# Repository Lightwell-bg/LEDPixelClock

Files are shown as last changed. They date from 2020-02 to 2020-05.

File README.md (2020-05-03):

# LED Pixel Clock (Clock, alarms, temperature, humidity, atmospheric pressure, and remote monitoring)
Multifunctional clock based on ESP8266 and WS2811 addressable LEDs for Home Automation (IoT)

------------
## What is a LED Pixel Clock?
The LED Pixel Clock is a four digit clock made up of 30 WS2811 addressable LEDs (8 mm) arranged into a 7-segment display. It based on ESP8266 microcontroller and real-time clock DS3231. BME280 sensor provides a precise measurement of indoor temperature, humidity and barometric pressure. An Internet connection via Wi-Fi module helps to synchronize time with NTP servers. Data from sensors can be transmitted via MQTT protocol or displayed on popular monitoring service thingspeak.com. Clock adjustment and manipulation is performed via WEB-interface.

# Features include:
- Always precise time because of synchronization with NTP time servers
- Indoor temperature, humidity and barometric pressure measurement
- Sending temperature, humidity and barometric pressure data to MQTT and Thingspeak.com server
- No buttons – control the clock via WEB-interface from PC, tablet or smartphone
- High display brightness
- Seven colors to display information
- Brightness adjustment
- Two alarm clocks
- Firmware update via Wi-Fi
- Information display on 3 languages: English, Russian, Bulgarian
- An option to install different alternative Open Source firmware
- Powered via USB
- Hackable: Open source hardware and firmware, Displays information read via UART

## Required Parts:
- Wemos D1 Mini: http://got.by/40d3u7
- RGB LED with WS2811 8mm http://ali.pub/4h4ehf
- BME280 Digital Sensor (Temperature, Humidity, Barometric Pressure) 5V: http://got.by/40d52x
- TTP223B digital touch capacitive sensor: http://got.by/40d6kz
- DS3231 AT24C32 IIC Module Precision Clock http://got.by/42k10g
- Active Buzzer http://got.by/42k1sg

Note: Using the links provided here help to support these types of projects. Thank you for the support.

**You can purchase a PCB with soldered elements and connectors for connecting the indicator and sensors, or just a PCB and a set of elements for installation**
https://diy.led-lightwell.eu/product/led-pixel-clock-shield-for-esp8266/

## Schematics / Assembly
| Component  | Pins  |  Wemos D1 Mini |
| --- | --- | --- |
| **RGB LED with WS2811**  |  Din -->|D5 (GPIO14)|
||+5V -->||
||GND --> | |
|**DS3231**|SCL -->|D1 (GPIO5)|
||SDA -->|D2 (GPIO4)|
||+3V||
||GND||
|**BME280**|SCL -->|D1 (GPIO5)|
||SDA -->|D2 (GPIO4)|
||+5V||
||GND||
|**Buzzer (active)**|+ -->|D8 (GPIO15)|
||GND||
|**TTP223B digital touch capacitive  sensor**|Dout -->|D6 (GPIO12)|
||+5V||
||GND||

## Power Supply
You must use a power supply 5V with a capacity of 2 A or more.

## Loading Supporting Library Files in Arduino
The following packages and libraries are used (download and install):
- ArduinoJson by Benoit Blanchon (version 6.13.0)
- TimeLib by Paul Stoffregen (version 1.5)
- PubSubClient by Nick O'Leary (version 2.7)
- RTClib by Adafruit  (version 1.3.3)
- Adafruit Unified Sensor by Adafruit (version 1.0.3) (for DHT sensor only)
- DHT sensor library by Adafruit (version 1.3.8) (for DHT sensor only)
- BlueDot BME280 Library by BlueDot (version 1.0.9)
- NetCrtESP (version 1.0) https://github.com/Lightwell-bg/NetCrtESP
- ESPTimeFunc (version 1.0) https://github.com/Lightwell-bg/ESPTimeFunc

Note: There could be some Issues if using different versions of the libraries.

## Initial Configuration
Starting with LW-Clock editing the Config.h file is optional. SSID and password for Wi-Fi, all API Keys are managed in the Web Interface. It is not required to edit the Config.h file before loading and running the code.
This project requires SPIFFS for saving and reading configuration settings
Use an external power supply with a capacity of 2 A or more!
**NOTE:** The settings in the Config.h are the default settings for the first loading. After loading you can change the settings via the Web Interface. If you want to change settings again in the Config.h, you will need to erase the file system on the Wemos or use the “Reset Settings” option in the Web Interface. During the first time run, Wemos D1 mini will try to connect to your Wi-Fi and fail (because it doesn't have any previously saved Wi-Fi credentials). This will cause it to start up an access point, which serves up a captive configuration portal. You can connect to this access point to select and enter credentials for your network. Save configuration and restart device. (Wemos D1 mini will restart and connect to your Wi-Fi network)

## Web Interface
All clock management is carried out using a web browser. On first power-up, LED Pixel Clock will serve a hotspot called LW-Clock. For clock adjustment and manipulation open a webpage with the 192.168.4.1 address. Within this hotspot you can manually override the time and date, set color, set timecodes of messages output and update software.

For Wi-Fi network connection please input its SSID and password. After successful connection LED Pixel Clock will begin to receive and transmit information over the Internet. NTP servers are used to get accurate time. To transmit temperature, humidity and barometric pressure data you can use the MQTT server https://www.cloudmqtt.com/ and the server https://thingspeak.com.

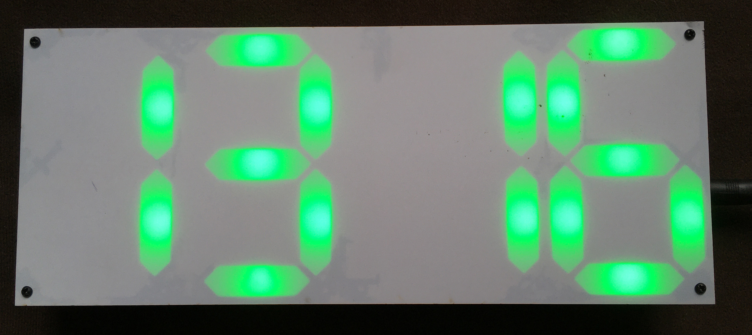
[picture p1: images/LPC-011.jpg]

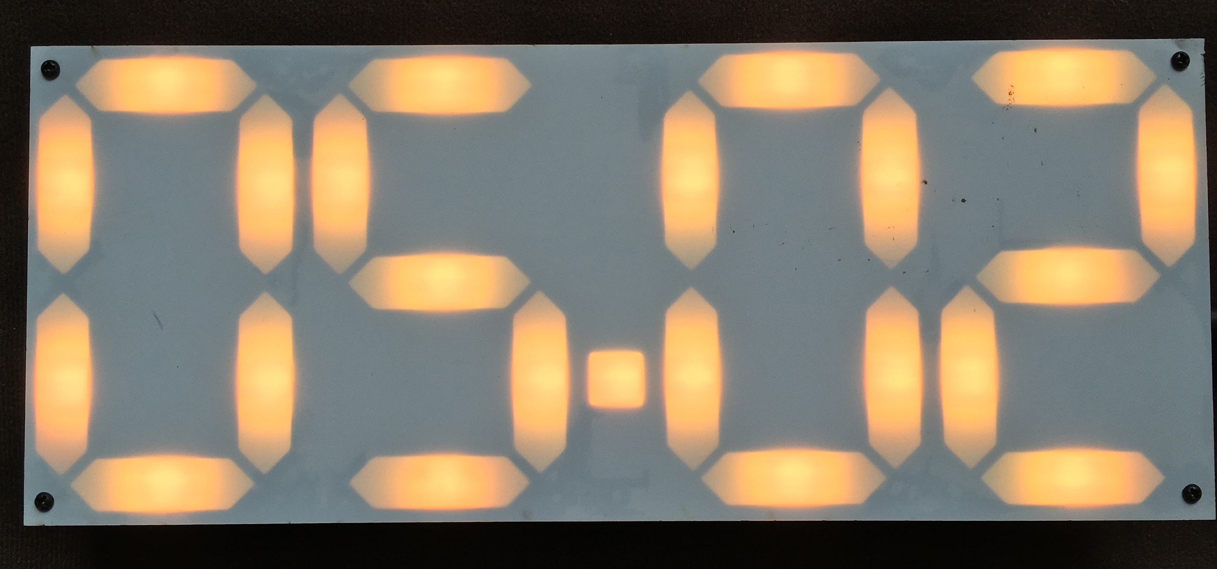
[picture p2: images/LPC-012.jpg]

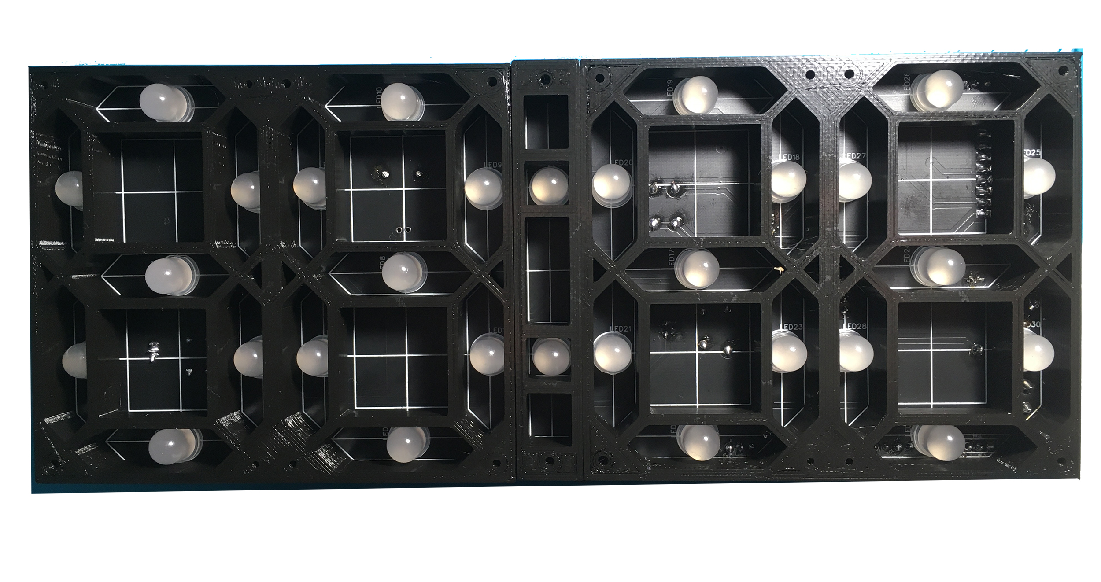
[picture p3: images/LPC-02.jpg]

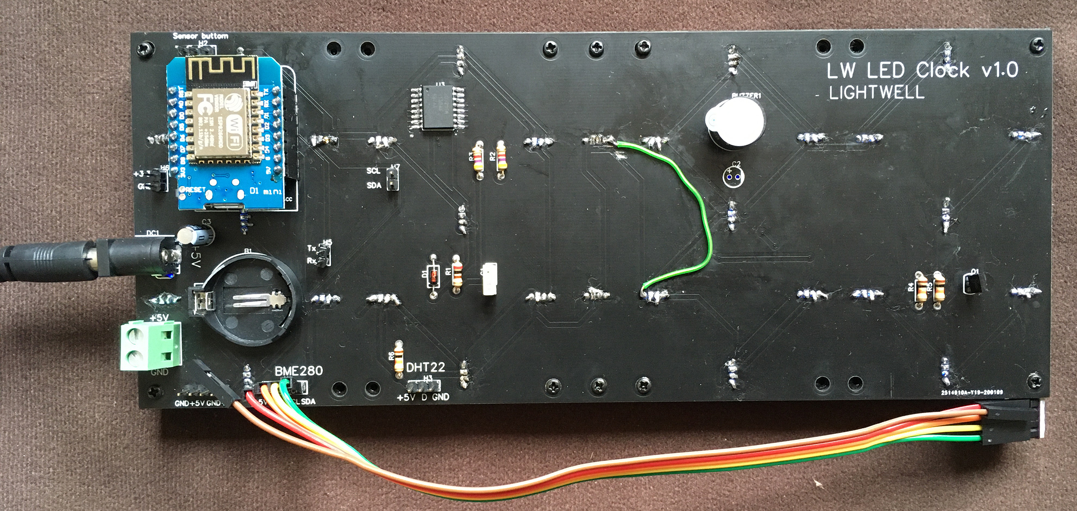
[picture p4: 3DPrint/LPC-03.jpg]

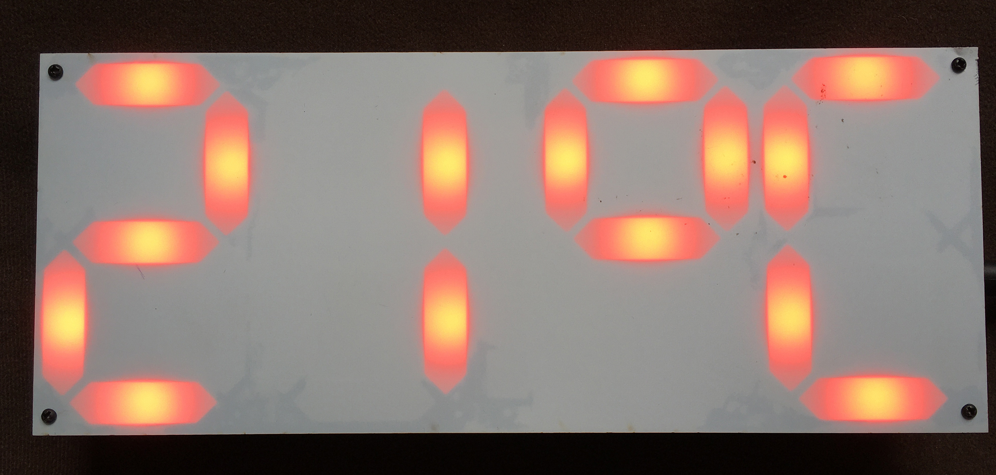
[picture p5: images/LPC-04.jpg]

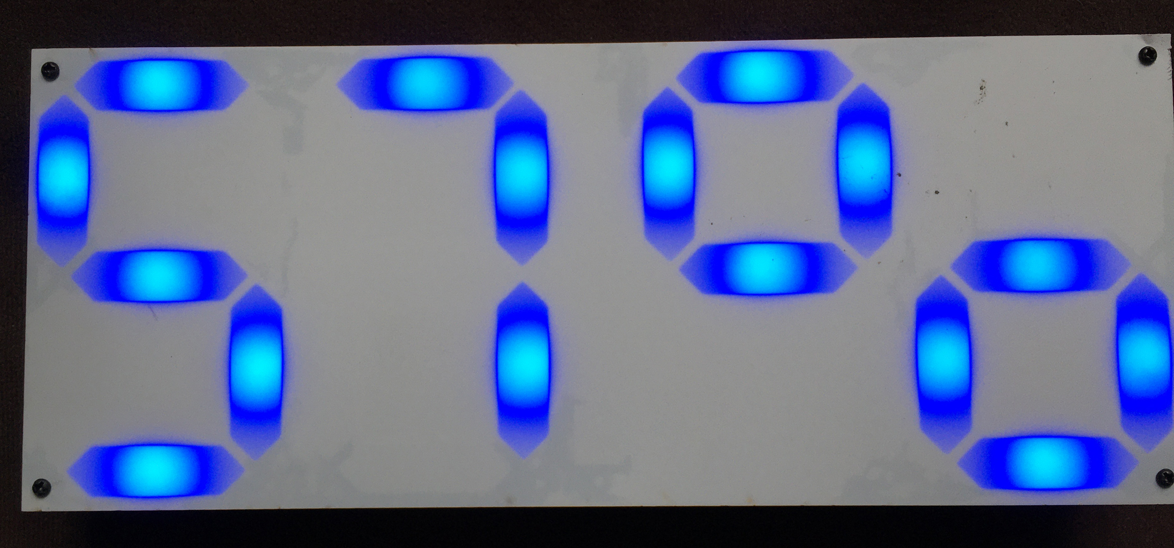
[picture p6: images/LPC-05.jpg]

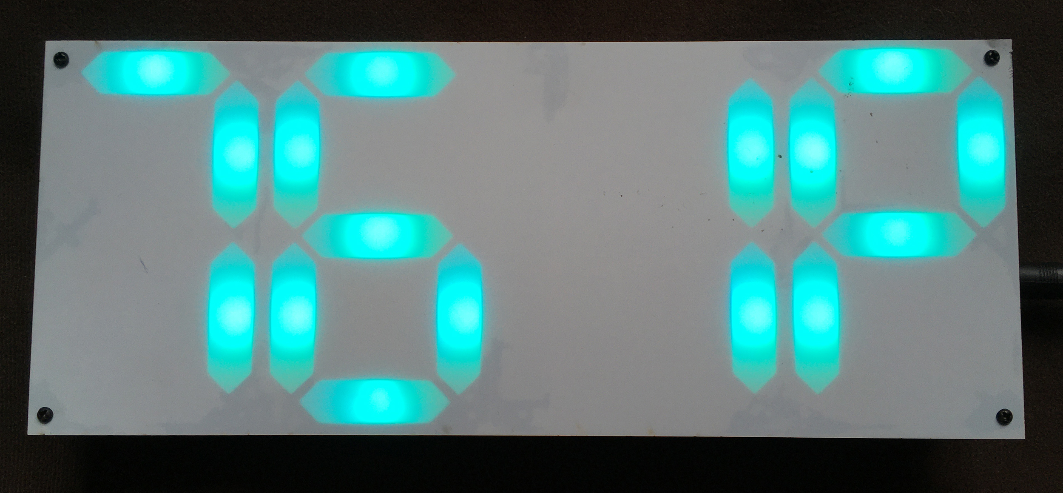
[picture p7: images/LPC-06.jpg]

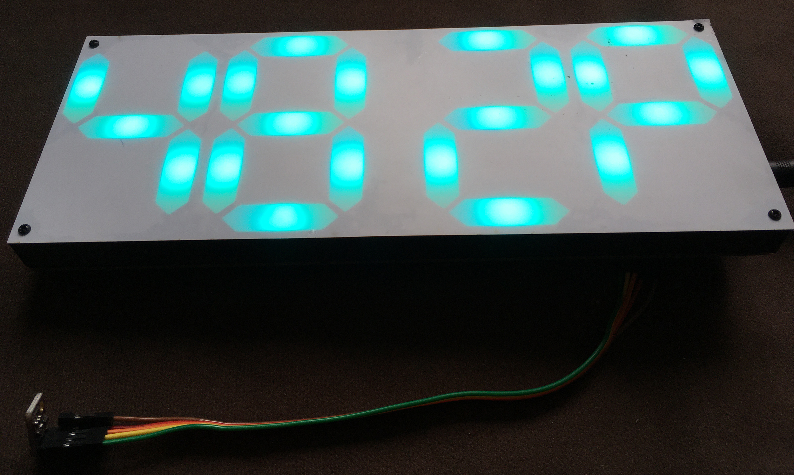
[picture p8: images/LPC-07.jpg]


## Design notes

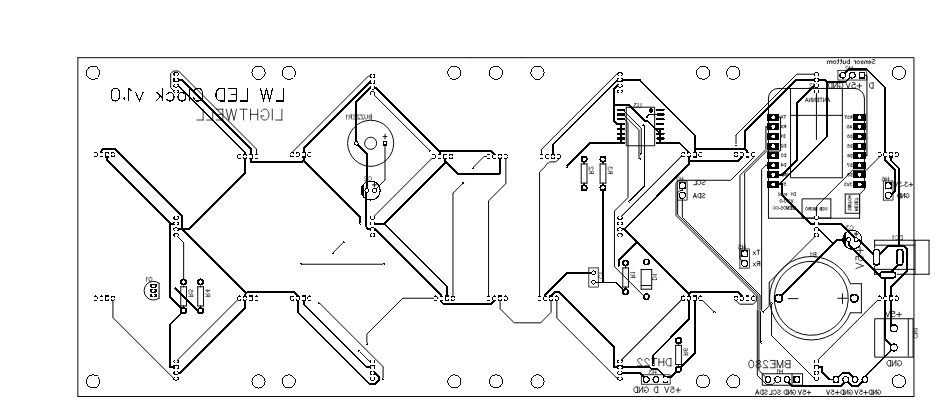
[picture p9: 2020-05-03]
Schematic&PCB/PCB2.png

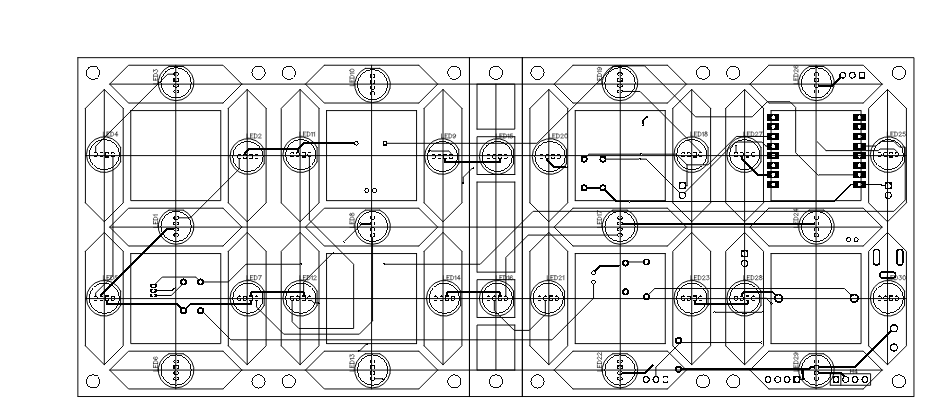
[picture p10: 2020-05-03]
Schematic&PCB/PCB1.png

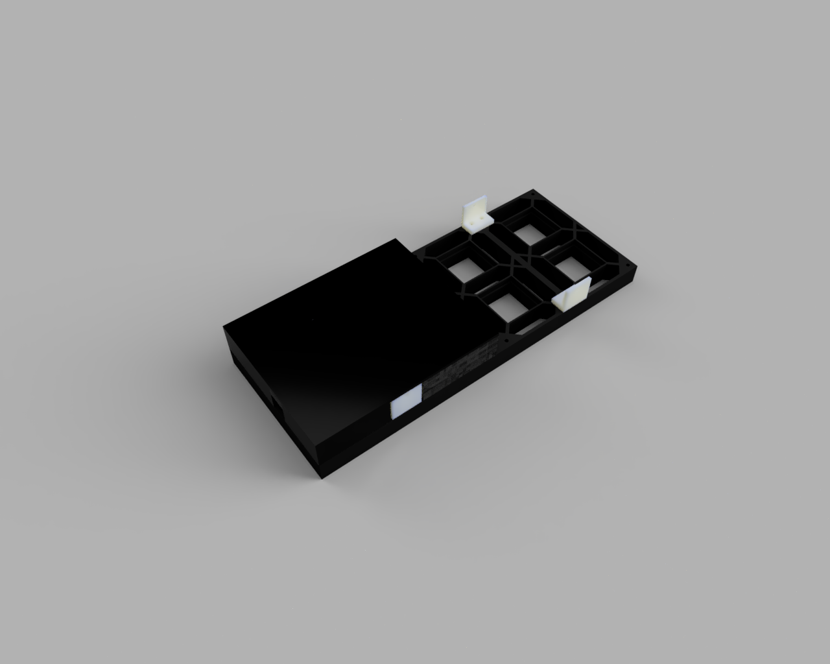
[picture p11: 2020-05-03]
images/rander.png

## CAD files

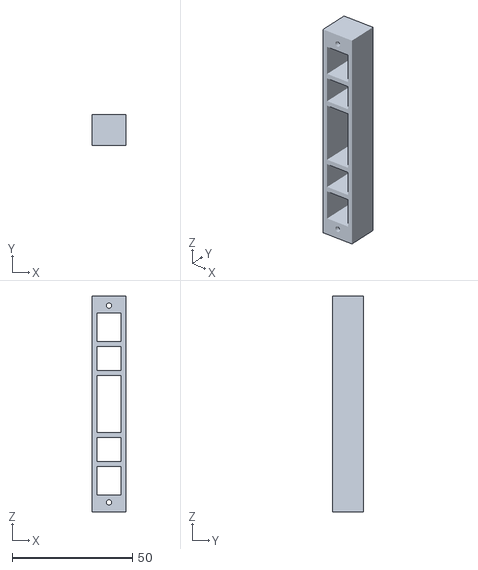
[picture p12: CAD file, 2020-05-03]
3DPrint/Dot.stl
14.0 x 13.0 x 89.7

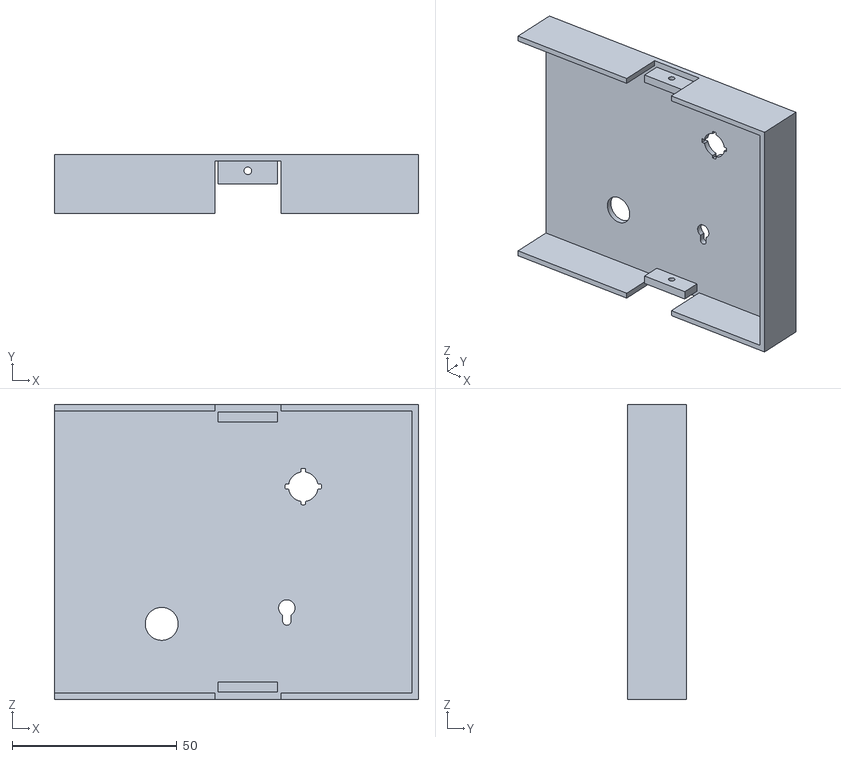
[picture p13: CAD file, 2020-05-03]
3DPrint/Back2.stl
110.6 x 18.0 x 89.7

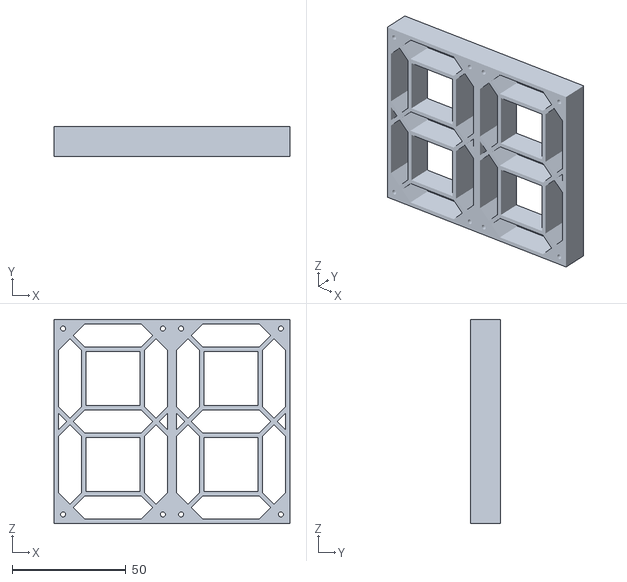
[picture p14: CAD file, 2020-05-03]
3DPrint/Segment2.stl
103.7 x 13.0 x 89.7

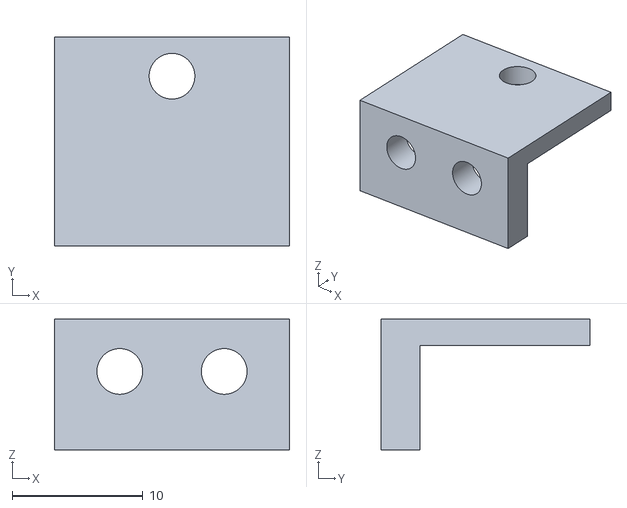
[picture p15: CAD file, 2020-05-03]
3DPrint/Part1-4.stl
18.0 x 16.0 x 10.0

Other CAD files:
3DPrint/Back1.stl

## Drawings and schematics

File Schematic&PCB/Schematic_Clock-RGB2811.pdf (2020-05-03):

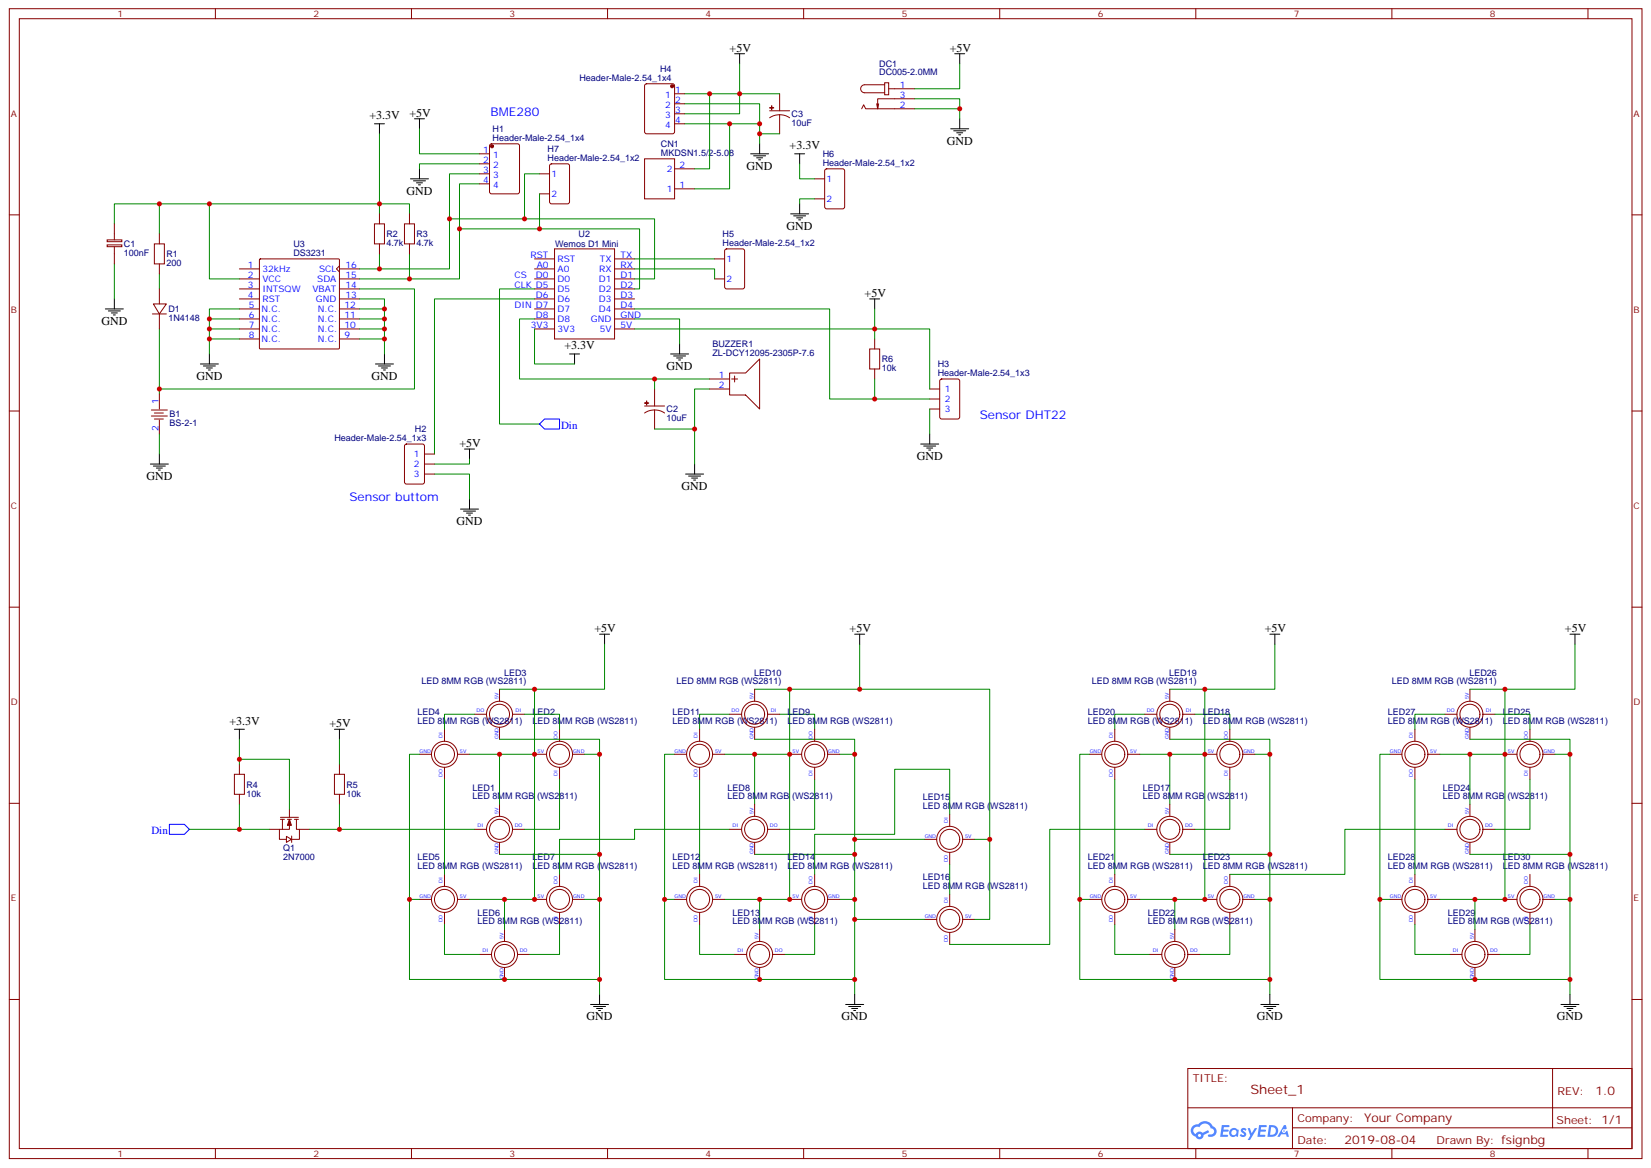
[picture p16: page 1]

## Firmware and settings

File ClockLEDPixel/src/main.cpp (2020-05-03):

#include <Arduino.h>
#include "config.h" 
#include "configFile.h"
#include "sensor.h"
#include "httpServer.h"
#include "mqtt.h"
#include "thingspeak.h"
#include "display.h"
#include "fwareupd.h"

void setup() {
    Serial.begin(115200);
    char host[16];
    snprintf(host, 12, "ESP%08X", ESP.getChipId());    
    if(!SPIFFS.begin()) { // Initialize SPIFFS
        Serial.println("An Error has occurred while mounting SPIFFS");
        return;
    } 
    loadConfig(); Serial.println(F("FileConfig init"));
    myWIFI.begin(ssid.c_str(), password.c_str(), SSDP_Name.c_str(), ssidAP.c_str(), passwordAP.c_str(), apIP.c_str()); Serial.println(F("Wi-Fi init"));
    Serial.printf("Ready! Open http://%s.local in your browser\n", host); 
    myESPTime.begin(timezone, isDayLightSaving, sNtpServerName, sNtpServerName2, sNtpServerName3, useRTC, updateRTCfromNTP); Serial.println(F("Start Time"));
    //myESPTime.setTimeRule(Last, Sun, Oct, 3, timezone*SECS_PER_HOUR, Last, Sun, Mar, 2, timezone*SECS_PER_HOUR+daylightOffset_sec);  
    init_firmWareUpdate(); Serial.println(F("Start init FirmWare update"));
    SSDP_Name = myWIFI.getNameSSDP(); Serial.println(SSDP_Name);
    mySSDP.begin(SSDP_Name.c_str(), "000000001", modelName.c_str(), nVersion.c_str(), "LIGHTWELL", "https://diy.led-lightwell.eu"); Serial.println(F("Start init SSDP"));
    init_HTTPServer(); Serial.println(F("HTTPServer init"));
    Serial.println(myWIFI.getDevStatusIP()); 
    init_sensor(); Serial.println(F("Sensor init"));
    init_mqtt();
    init_LStrip();  Serial.println(F("LED strip init"));
}

void loop() {
  struct tm tnow = myESPTime.getTimeStruct();
  static uint8_t sMode=0, oldsMode = 1;
  static uint32_t tCount = 0;
  static bool chMode = true;
  if (myESPTime.compTimeInt(global_start, global_stop, &tnow)) {
    if (sMode != oldsMode) {Serial.print(F("Mode ")); Serial.println(sMode); oldsMode = sMode;}
    if (myESPTime.compTimeInt(dmodefrom, dmodeto, &tnow))
        strip.setBrightness(map(brightd, 0, 15, 100, 255));
        else strip.setBrightness(map(brightn, 0, 15, 100, 255));
    if (millis()-tCount > intShowData) {sMode++; chMode = true; tCount = millis();}
    if (onlyClockNight && !myESPTime.compTimeInt(dmodefrom, dmodeto, &tnow)) sMode = 1; //Show only Clock Night
      if (sMode > maxMode) {sMode = 1;}
      if (sMode==1) {
        if (isLedClock && myESPTime.compTimeInt(clockFrom, clockTo, &tnow)) {
          showTime();
        }
        else sMode++;
      }
      if (sMode==2 && chMode) {
        if (isLedDate && myESPTime.compTimeInt(dateFrom, dateTo, &tnow)) {
          showDate(); chMode = false;
        }
        else sMode++;
      }
      if (sMode==3 && chMode) {
        if (isLedTemp && myESPTime.compTimeInt(tempFrom, tempTo, &tnow)) {        
          showTemp(); chMode = false;
        }
        else sMode++;
      }
      if (sMode==4 && chMode) {
        if (isLedHum && myESPTime.compTimeInt(humFrom, humTo, &tnow)) {        
          showHum(); chMode = false;
        }
        else sMode++;
      }
      if (sMode==5 && chMode) {
        if (isLedPres && myESPTime.compTimeInt(presFrom, presTo, &tnow)) {        
          showPres(); chMode = false;
        }
        else sMode++;
      }
  }
  if (tspeakOn) {
      sendTspeak(TSPEAK_SEND_INT);
  }
  if (mqttOn) {
      mqttReconnect(60000);
      sendTHP(MQTT_SEND_INT);
  }
  delay(1); //Вроде нужна для восстановления стека
  yield();
}

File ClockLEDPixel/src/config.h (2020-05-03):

#ifndef GLOBAL_H
#define GLOBAL_H
const String modelName = "LEDPixelClock";
const String nVersion = "v1.0";
#define USE_DHT false //USE OR NO
#define USE_BME280 true //USE OR NO

#include <ESP8266WiFi.h>
#include <ESPAsyncTCP.h>
#include "FS.h"
#include <Updater.h>//for update firmware
#include <ESP8266SSDP.h>
#include <ESPAsyncWebServer.h>
#include <ArduinoJson.h>
#include <SPI.h>
#include <Wire.h> // must be included here so that Arduino library object file references work
#include <PubSubClient.h> //"https://github.com/knolleary/pubsubclient.git"
#include <Adafruit_NeoPixel.h>
#include "NetCrtESP.h"
#include "ESPTimeFunc.h"
#include "ssdpAWS.h"

bool useRTC = true; //get time RTC

AsyncWebServer HTTP(80);
WiFiClient ESPclient;
PubSubClient mqttClient(ESPclient);
NetCrtESP myWIFI;
ESPTimeFunc myESPTime(useRTC);
ssdpAWS mySSDP(&HTTP);

String cVersion = modelName + nVersion;

#if USE_DHT == true
  #include <Adafruit_Sensor.h> // https://github.com/adafruit/Adafruit_Sensor
  #include "DHT.h" //https://github.com/adafruit/DHT-sensor-library
  //#define DHTTYPE DHT21   // DHT 21 (AM2301)
  #define DHTTYPE DHT22   // DHT 22  (AM2302), AM2321
  #define TEMPHUM_PIN 4    // D4 выберите входной контакт,к которому подключен датчик
  DHT dht(TEMPHUM_PIN, DHTTYPE);
  //cVersion += " DHT22 ";
#endif //DHT
#if USE_BME280 == true // I2C D1, D2
  #include "BlueDot_BME280.h"
  BlueDot_BME280 bme280 = BlueDot_BME280(); 
  //cVersion += String(" BME280"); 
#endif //BME280
  
#define LED_PIN 14 // D5
#define LED_COUNT 30 //7*4+2
Adafruit_NeoPixel strip(LED_COUNT, LED_PIN, NEO_RGB + NEO_KHZ800);

String filePath = "/myConfig.json"; //File for config
String jsonConfig = "{}";

// wifi
String ssid = "";
String password = "";
String ssidAP = "LED2811";   // SSID AP точки доступа
String passwordAP = ""; // пароль точки доступа
String SSDP_Name = "LED2811"; // Имя SSDP
//IPAddress apIP(192, 168, 4, 1);
String apIP = "192.168.4.1";

uint8_t lang = 2; //0-RU, 1-BG, 2 -EN, 3-UA
//Time
//const unsigned long TIME_UPDATE = 1000*60*10; //Интервал обновления времени
int8_t timezone = 2;               // часовой пояс GTM
String sNtpServerName = "us.pool.ntp.org";
const char sNtpServerName2[] = "pool.ntp.org";
const char sNtpServerName3[] = "time.nist.gov";
bool isDayLightSaving = false; //Summer time use
bool updateRTCfromNTP = true; //


//LED Strip
uint8_t maxMode = 5;
uint32_t intShowData = 3000;
uint8_t clockColor = 2;
uint8_t dateColor = 1;
uint8_t tempColor = 3;
uint8_t humColor = 4;
uint8_t presColor = 5;
const uint32_t offColor = strip.Color(0, 0, 0);
uint8_t digits[14][7] = {{0,1,1,1,1,1,1},  // Digit 0
                        {0,1,0,0,0,0,1},   // Digit 1
                        {1,1,1,0,1,1,0},   // Digit 2
                        {1,1,1,0,0,1,1},   // Digit 3
                        {1,1,0,1,0,0,1},   // Digit 4
                        {1,0,1,1,0,1,1},   // Digit 5
                        {1,0,1,1,1,1,1},   // Digit 6
                        {0,1,1,0,0,0,1},   // Digit 7
                        {1,1,1,1,1,1,1},   // Digit 8
                        {1,1,1,1,0,1,1},  // Digit 9 | 2D Array for numbers on 7 segment
                        {1,1,1,1,0,0,0},   // ° char
                        {0,0,1,1,1,1,0},   // C char
                        {1,0,0,0,1,1,1},  // % char
                        {1,1,1,1,1,0,0}};  // P char
uint8_t brightd = 15, brightn = 2; //brightness day and night
uint8_t dmodefrom = 8, dmodeto = 20; //DAY MODE
bool autoBright = false; //reserv
//show
bool onlyClockNight = false;
bool isLedClock = true, isLedDate = true, isLedTemp = true, isLedHum = false, isLedPres = false;
float clockFrom=0, dateFrom=0, tempFrom=0, humFrom=0, presFrom=0;
float clockTo=24, dateTo=24, tempTo=24, humTo=24, presTo=24; 
float global_start = 0, global_stop = 24; //Working time

enum edataArrType {
  STIME,
  SDATE,
  STEMP,
  SHUM,
  SPRES
};
//edataArrType dataArrType;
//MQTT
char mqttData[80]; //Данные для передачи на MQTT
bool mqttOn = false;
String mqtt_server = "hairdresser.cloudmqtt.com"; // Имя сервера MQTT
int mqtt_port = 18695; // Порт для подключения к серверу MQTT
String mqtt_user = ""; // Логи от сервер
String mqtt_pass = ""; // Пароль от сервера QvKr_jbEsHYb
String mqtt_name = "LED2811"; 
String mqtt_Temp = mqtt_name + "/temp";
String mqtt_Hum = mqtt_name + "/hum";
String mqtt_Pres = mqtt_name + "/pres";
String mqtt_Timezone = "timezone";
const unsigned long MQTT_SEND_INT = 1000*60*11; //Интервал отправки на MQTT
//thingspeak.com
bool tspeakOn = false;
String tspeak_server = "api.thingspeak.com";
unsigned long tspeak_channal = 9633;
String tspeak_wapi = "";  
const unsigned long TSPEAK_SEND_INT = 1000*60*10;

#endif

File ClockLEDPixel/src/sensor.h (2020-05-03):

void init_sensor() {
#if USE_DHT == true
  dht.begin(); 
#endif //DHT
#if USE_BME280 == true // I2C D1, D2
  bme280.parameter.communication = 0;                  //Choose communication protocol
  bme280.parameter.I2CAddress = 0x76;                  //Choose I2C Address 0x77
  //0b00:     In sleep mode no measurements are performed, but power consumption is at a minimum
  //0b01:     In forced mode a single measured is performed and the device returns automatically to sleep mode
  //0b11:     In normal mode the sensor measures continually (default value)
  bme280.parameter.sensorMode = 0b11; 
  bme280.parameter.IIRfilter = 0b100;                    //Setup for IIR Filter
  bme280.parameter.humidOversampling = 0b101;            //Setup Humidity Oversampling
  bme280.parameter.tempOversampling = 0b101;             //Setup Temperature Ovesampling
  bme280.parameter.pressOversampling = 0b101;            //Setup Pressure Oversampling 
  bme280.parameter.pressureSeaLevel = 1013.25;           //default value of 1013.25 hPa
  bme280.parameter.tempOutsideCelsius = 15;              //default value of 15°C
  uint8_t tries = 10;
  while (--tries && bme280.init() != 0x60) {
    Serial.println(F("Ops! BME280 could not be found! Please check your connections."));
    delay(500);
  }
  if (tries > 0) {
    Serial.println(F("BME280 detected!"));
  }
#endif //BME280 
}

#if USE_DHT == true
String getTempDHT() {
  float h = dht.readHumidity(); 
  float t = dht.readTemperature(); 
  if (isnan(t) || isnan(h))  {
    Serial.println("Failed to read Temp from DHT");
    return "";
  }
  else {
    // Compute heat index in Celsius (isFahreheit = false)
    float hic = dht.computeHeatIndex(t, h, false);
    String tempDHT = String(hic, 1); 
    Serial.print("Temperature: "); Serial.print(tempDHT); Serial.println("°C");     
    return tempDHT;      
  }
}

String getHumDHT() {
  float h = dht.readHumidity(); 
  if (isnan(h))  {
    Serial.println("Failed to read Hum from DHT");
    return "";
  }
  else {
    // Compute heat index in Celsius (isFahreheit = false)
    String humDHT = String(h, 0); 
    Serial.print("Humidity: "); Serial.print(humDHT); Serial.println("%");     
    return humDHT;      
  }
}
#endif //DHT

#if USE_BME280 == true // I2C D1, D2
int getTempBME280() {
  float tempBME = bme280.readTempC()*10;
  Serial.print("Temperature: "); Serial.print(tempBME/10); Serial.println("°C"); 
  return (int)round(tempBME);
}

String getStrTempBME280() {
  float tempBME = bme280.readTempC();
  Serial.print("Temperature: "); Serial.print(tempBME); Serial.println("°C"); 
  return String(tempBME, 1);
}

int getHumBME280() {
  float humBME = bme280.readHumidity();
  Serial.print("Humidity: "); Serial.print(humBME); Serial.println("%"); 
  return (int)round(humBME);  
}

String getStrHumBME280() {
  float humBME = bme280.readHumidity();
  Serial.print("Humidity: "); Serial.print(humBME); Serial.println("%"); 
  return String(humBME, 0);  
}

int getPressBME280() {
  float pressBME = bme280.readPressure();
  Serial.print(F("Pressure "));Serial.print(pressBME);Serial.println(" hPa");
  Serial.print(F("Pressure "));Serial.print(pressBME*0.750062);Serial.println(" mm");
  Serial.print(F("Altitude in Meters:\t\t")); Serial.println(bme280.readAltitudeMeter());
  return (int)round(pressBME*0.750062);  
}

String getStrPressBME280() {
  float pressBME = bme280.readPressure();
  Serial.print(F("Pressure "));Serial.print(pressBME);Serial.println(" hPa");
  Serial.print(F("Pressure "));Serial.print(pressBME*0.750062);Serial.println(" mm");
  Serial.print(F("Altitude in Meters:\t\t")); Serial.println(bme280.readAltitudeMeter());
  return String(pressBME*0.750062,0);  
}
#endif //BME280 

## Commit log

2020-05-03 new file: 3DPrint/Back1.stl new file: 3DPrint/Back2.stl modified: 3DPrint/Dot.stl modified: README.md
    [7-2.stl, Back1.stl, Back2.stl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]
2020-05-03 modified: README.md new file: Schematic&PCB/Gerber.zip new file: Schematic&PCB/Schematic_Clock-RGB2811.pdf
